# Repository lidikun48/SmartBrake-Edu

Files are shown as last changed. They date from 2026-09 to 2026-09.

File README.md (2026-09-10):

# SmartBrake Edu

SmartBrake Edu adalah prototipe sistem telemetri pengereman berbasis ESP32 yang dikembangkan untuk membantu observasi praktik pengereman sepeda motor pada pelatihan *safety riding*. Sistem memperoleh data tekanan rem depan dan belakang dalam bentuk persentase relatif, membaca kecepatan roda depan dan belakang, menghitung distribusi penggunaan rem F:R, serta menampilkan dan merekam data melalui Web Dashboard pada jaringan Wi-Fi lokal.

Repository ini digunakan sebagai dokumentasi teknis source code dan desain perangkat keras SmartBrake Edu.

## Fitur Utama

- Pembacaan tekanan rem depan dan belakang dalam skala relatif 0–100%.
- Kalibrasi relatif menggunakan metode **Set Zero–Set Max**.
- Pembacaan kecepatan roda depan dan belakang menggunakan sensor *magnetic pickup*.
- Perhitungan distribusi penggunaan rem depan dan belakang (F:R).
- ESP32 sebagai *local access point* dan Web Server.
- Web Dashboard responsif untuk smartphone, tablet, dan laptop.
- Data Logger berbasis browser.
- Brake Test History dan Session Manager.
- Grafik kecepatan dan tekanan selama sesi.
- Brake Event Timeline dan Distribution History.
- Ekspor data hasil sesi.
- Penyimpanan konfigurasi perangkat menggunakan Preferences/NVS.
- Pembaruan firmware melalui OTA.

## Arsitektur Singkat

```text
Sensor Tekanan Depan & Belakang
            |
            v
       Pembacaan ADC
            |
            v
         Filter EMA
            |
            v
   Kalibrasi Relatif
     Set Zero–Set Max
            |
            v
 Persentase Tekanan 0–100%
            |
            +----------------------+
                                   |
Sensor Magnetic Pickup F/R        |
            |                      |
            v                      |
      Pembacaan Pulsa              |
            |                      |
            v                      |
 Perhitungan Kecepatan             |
            |                      |
            +----------+-----------+
                       |
                       v
                     ESP32
                       |
                       v
              Wi-Fi Lokal / HTTP
                       |
                       v
                 Web Dashboard
                       |
                       v
                  Data Logger
```

## Perangkat Keras Utama

- ESP32 DevKit V1
- 2 sensor tekanan hidrolik
- 2 sensor *magnetic pickup*
- PC817 pada antarmuka sensor kecepatan
- rangkaian pengondisi sinyal analog
- LED indikator sistem dan sensor
- sistem catu daya portabel

## Konfigurasi GPIO

| Fungsi | GPIO |
|---|---:|
| Sensor tekanan depan | 32 |
| Sensor tekanan belakang | 33 |
| Sensor kecepatan roda depan | 26 |
| Sensor kecepatan roda belakang | 27 |
| LED system | 2 |
| LED tekanan depan | 5 |
| LED tekanan belakang | 19 |
| LED kecepatan depan | 3 |
| LED kecepatan belakang | 22 |

## Struktur Repository

```text
SmartBrake-Edu/
├── README.md
├── platformio.ini
├── .gitignore
├── src/
│   └── main.cpp
├── docs/
│   ├── hardware/
│   │   └── README.md
│   ├── schematic/
│   │   ├── BrakePressure4.kicad_pro
│   │   ├── BrakePressure4.kicad_sch
│   │   ├── BrakePressure4.kicad_pcb
│   │   └── README.md
│   └── screenshots/
│       └── README.md
└── data/
    └── README.md
```

## Source Code

Firmware utama dan Web Dashboard berada pada:

```text
src/main.cpp
```

Web Dashboard disimpan di dalam firmware menggunakan `PROGMEM`, sehingga HTML, CSS, dan JavaScript berada pada file source yang sama dengan program ESP32.

## Pengembangan dengan PlatformIO

Project menggunakan framework Arduino pada PlatformIO untuk board ESP32 DevKit V1.

Build firmware:

```bash
pio run
```

Konfigurasi build dan metode upload terdapat pada `platformio.ini`.

### Upload USB

Untuk upload melalui kabel USB, gunakan `upload_protocol = esptool` pada `platformio.ini`.

### Upload OTA

Konfigurasi repository menyediakan pengaturan OTA menggunakan `espota` pada alamat lokal perangkat. Pastikan komputer telah terhubung ke jaringan SmartBrake Edu sebelum melakukan upload OTA.

## Konfigurasi Wi-Fi

Demi keamanan repository publik, password Access Point pada `src/main.cpp` menggunakan placeholder:

```cpp
const char* AP_PASS = "CHANGE_ME";
```

Ganti nilai tersebut dengan password yang akan digunakan pada perangkat sebelum melakukan build untuk penggunaan aktual. Jangan menyimpan password pribadi atau kredensial sensitif di repository publik.

## Desain KiCad

Berkas proyek KiCad tersedia pada folder [`docs/schematic`](docs/schematic):

- `BrakePressure4.kicad_sch`
- `BrakePressure4.kicad_pcb`
- `BrakePressure4.kicad_pro`

## Catatan Pengukuran

Nilai tekanan yang ditampilkan SmartBrake Edu merupakan **persentase tekanan relatif** berdasarkan kalibrasi Set Zero–Set Max. Sistem tidak dikalibrasi sebagai instrumen pengukuran tekanan absolut dalam satuan PSI, bar, atau MPa dan tidak mengukur gaya pengereman aktual pada bidang kontak ban dengan permukaan jalan.

Parameter kecepatan digunakan sebagai data pendukung untuk mengamati perubahan laju selama sesi dan tidak dinyatakan sebagai hasil pengukuran kecepatan terkalibrasi terhadap instrumen referensi.

## Konteks Akademik

SmartBrake Edu dikembangkan dalam Proyek Akhir Program Studi D4 Teknik Mesin Otomotif, Fakultas Vokasi, Universitas Negeri Yogyakarta.

**Pengembang:** Chiko Casillas  
**Tahun:** 2026

## Status Repository

- Firmware utama: tersedia.
- Web Dashboard: terintegrasi pada firmware.
- Skematik KiCad: tersedia.
- Layout PCB KiCad: tersedia.
- Konfigurasi PlatformIO: tersedia.
- Folder data dan dokumentasi tambahan: disiapkan untuk contoh data serta dokumentasi akademik yang dapat dipublikasikan.

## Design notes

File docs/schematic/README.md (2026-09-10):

# KiCad Hardware Design

Folder ini memuat berkas desain perangkat keras SmartBrake Edu yang digunakan untuk dokumentasi proyek.

## Berkas

- `BrakePressure4.kicad_sch` — skematik rangkaian SmartBrake Edu.
- `BrakePressure4.kicad_pcb` — layout PCB SmartBrake Edu.
- `BrakePressure4.kicad_pro` — berkas proyek KiCad.

Berkas preferensi lokal KiCad (`*.kicad_prl`) tidak disertakan karena tidak diperlukan untuk membuka atau meninjau desain utama.

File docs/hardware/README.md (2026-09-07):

# Hardware Documentation

Folder ini digunakan untuk dokumentasi perangkat keras SmartBrake Edu, termasuk konfigurasi GPIO, foto perangkat, proses perakitan, dan dokumentasi redesign.

Konfigurasi GPIO final:

| Fungsi | GPIO |
|---|---:|
| Sensor tekanan depan | 32 |
| Sensor tekanan belakang | 33 |
| Sensor kecepatan roda depan | 26 |
| Sensor kecepatan roda belakang | 27 |
| LED System | 2 |
| LED tekanan depan | 5 |
| LED tekanan belakang | 19 |
| LED kecepatan depan | 3 |
| LED kecepatan belakang | 22 |

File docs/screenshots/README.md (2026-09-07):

# Screenshots

Folder ini digunakan untuk dokumentasi tampilan Web Dashboard SmartBrake Edu.

Contoh dokumentasi yang dapat ditempatkan di sini:
- Dashboard utama;
- halaman Data Logger;
- grafik kecepatan dan tekanan;
- Brake Event Timeline;
- Distribution History;
- Session Manager;
- halaman Settings dan kalibrasi relatif.

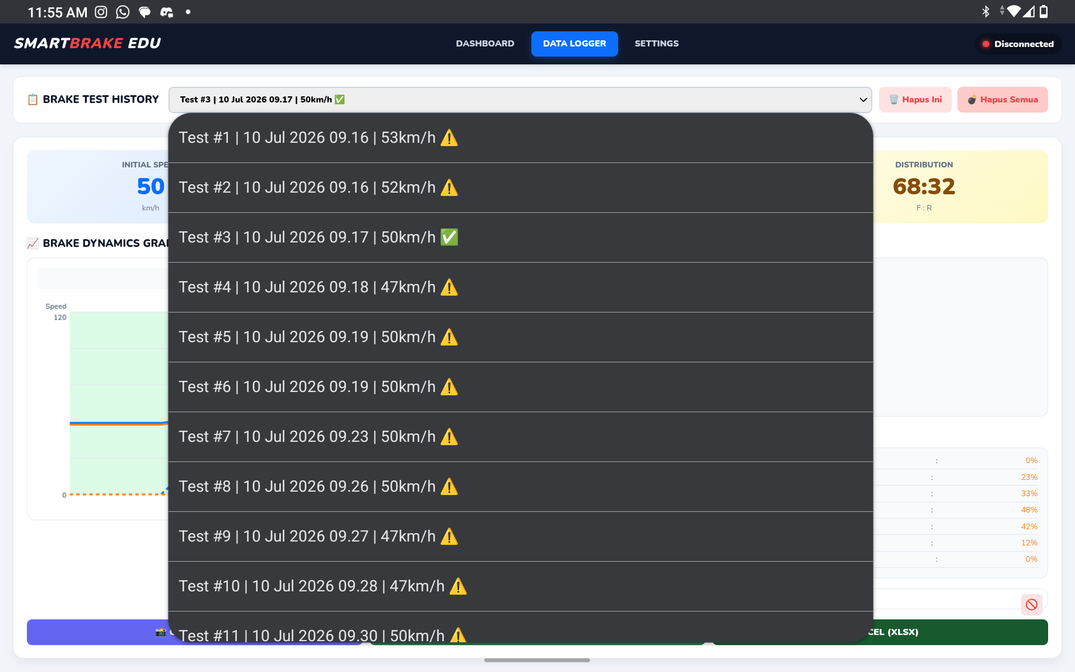
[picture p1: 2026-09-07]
docs/screenshots/Screenshot_20260830-115544.png

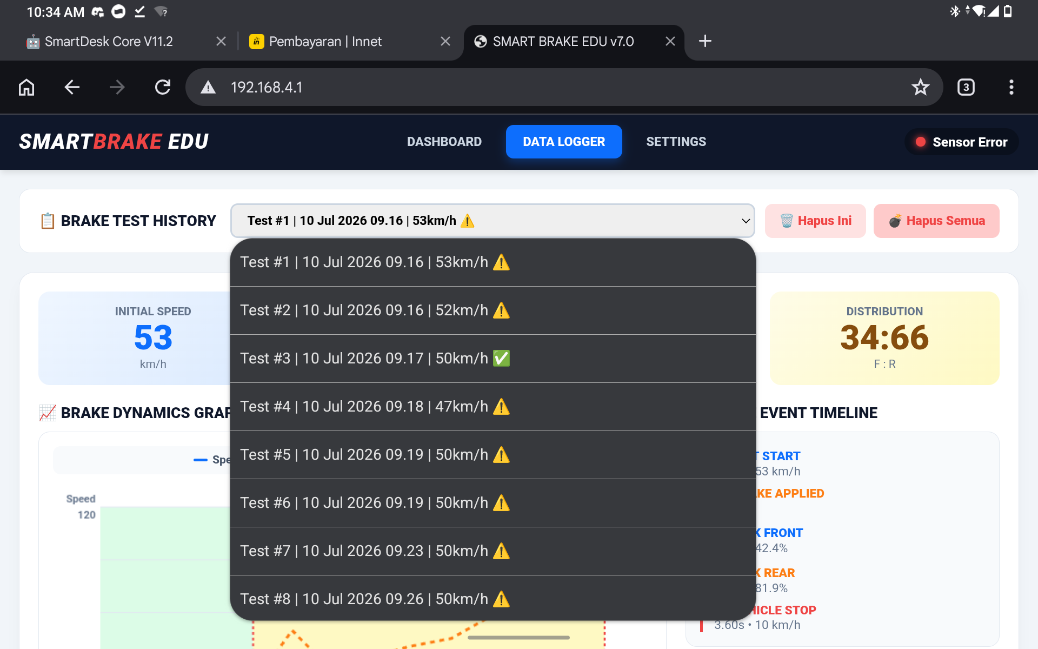
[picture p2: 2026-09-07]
docs/screenshots/Screenshot_20260823-103436.png

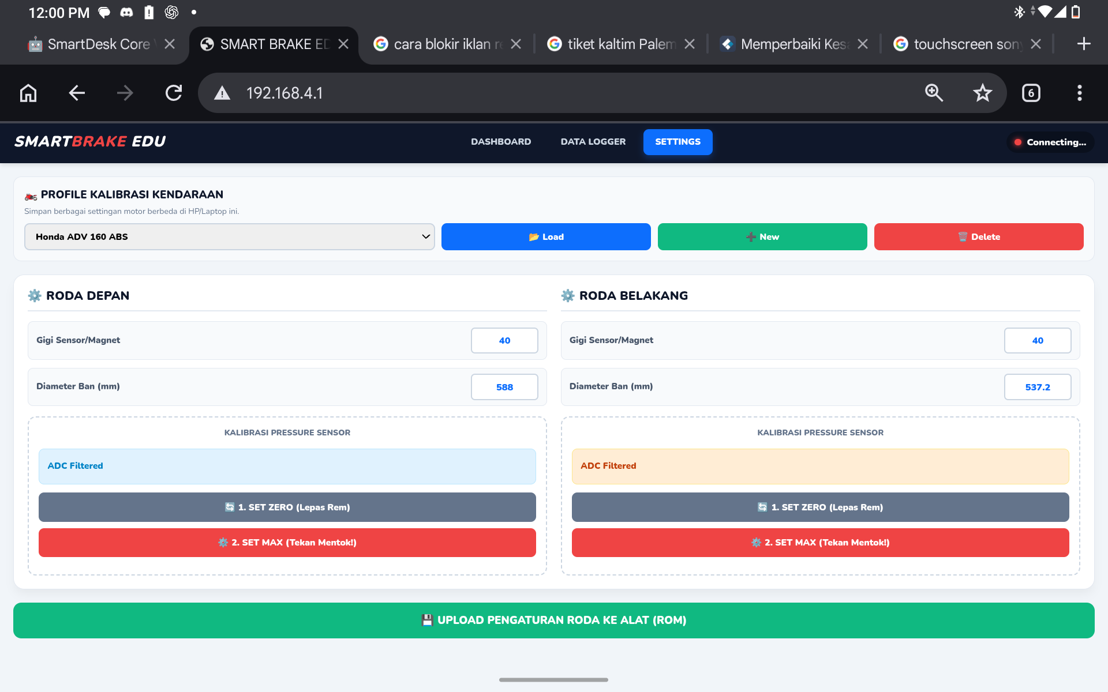
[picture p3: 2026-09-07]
docs/screenshots/Screenshot_20260826-120054.png

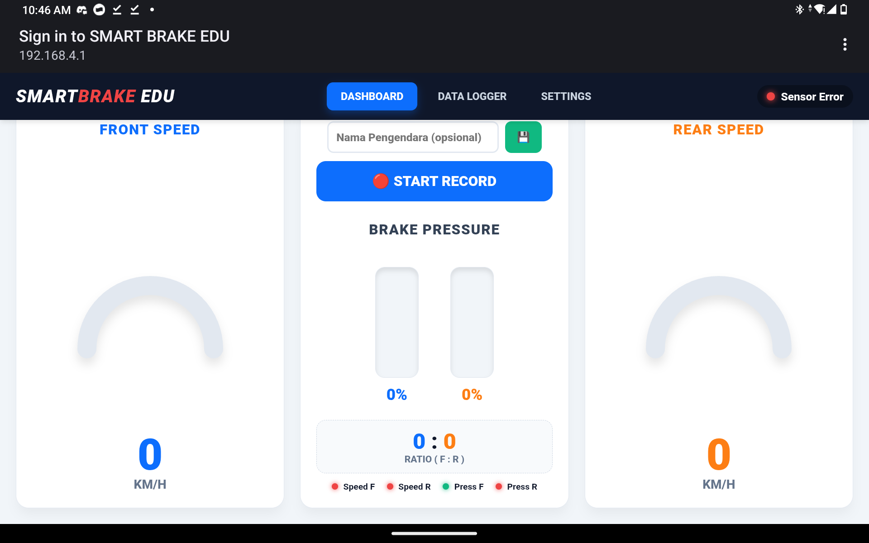
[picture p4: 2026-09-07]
docs/screenshots/Screenshot_20260823-104600.png

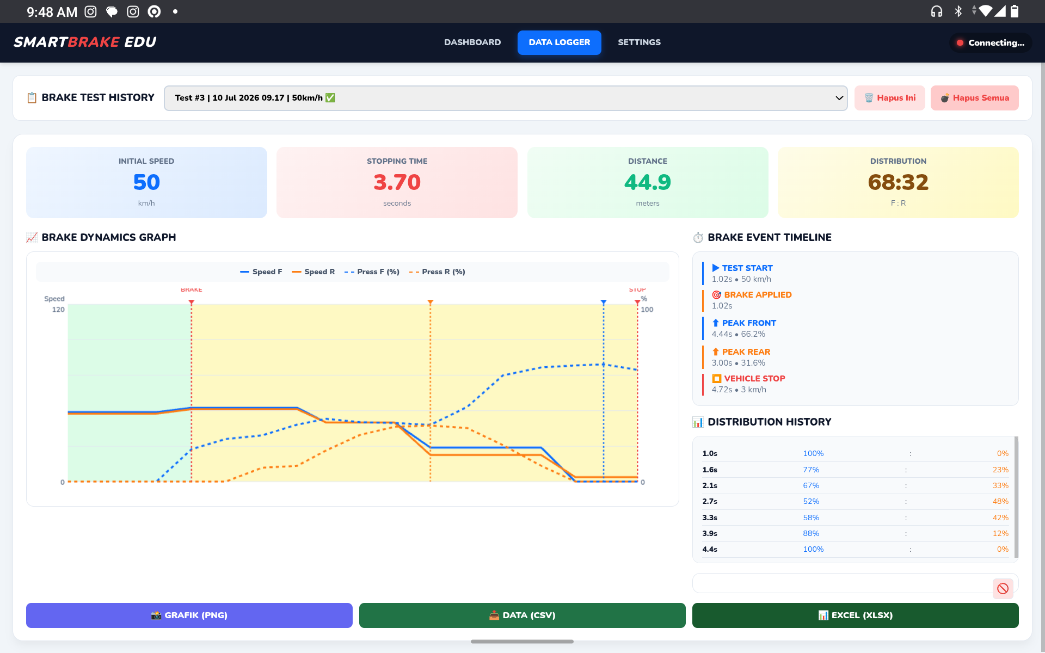
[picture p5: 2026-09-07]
docs/screenshots/Screenshot_20260831-094811.png

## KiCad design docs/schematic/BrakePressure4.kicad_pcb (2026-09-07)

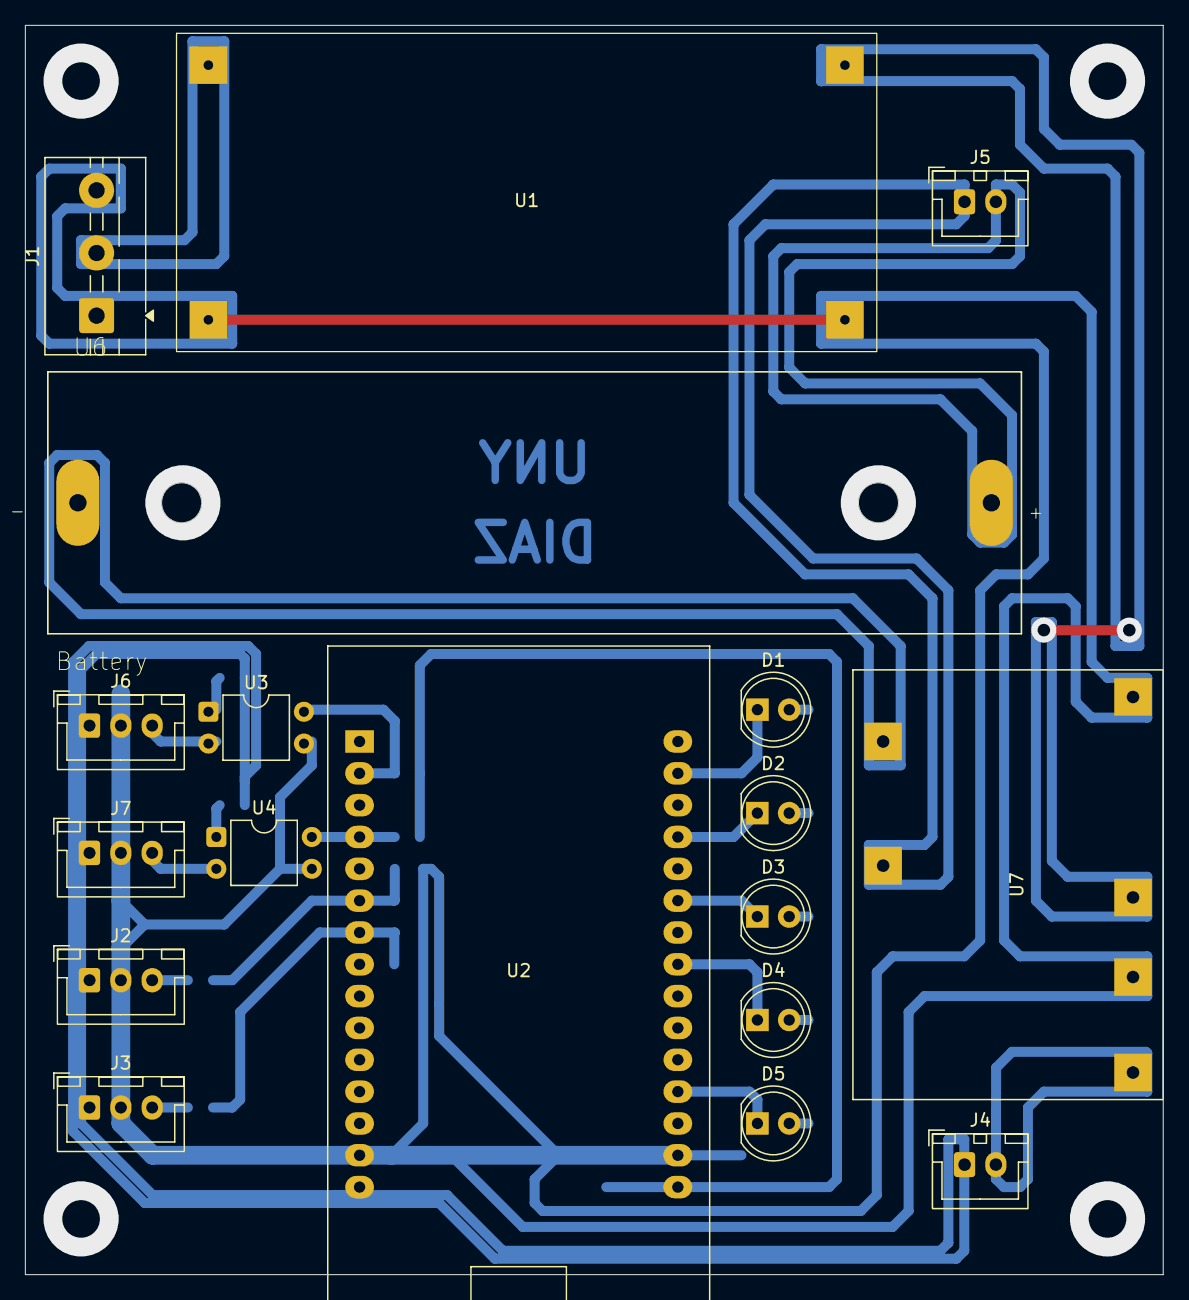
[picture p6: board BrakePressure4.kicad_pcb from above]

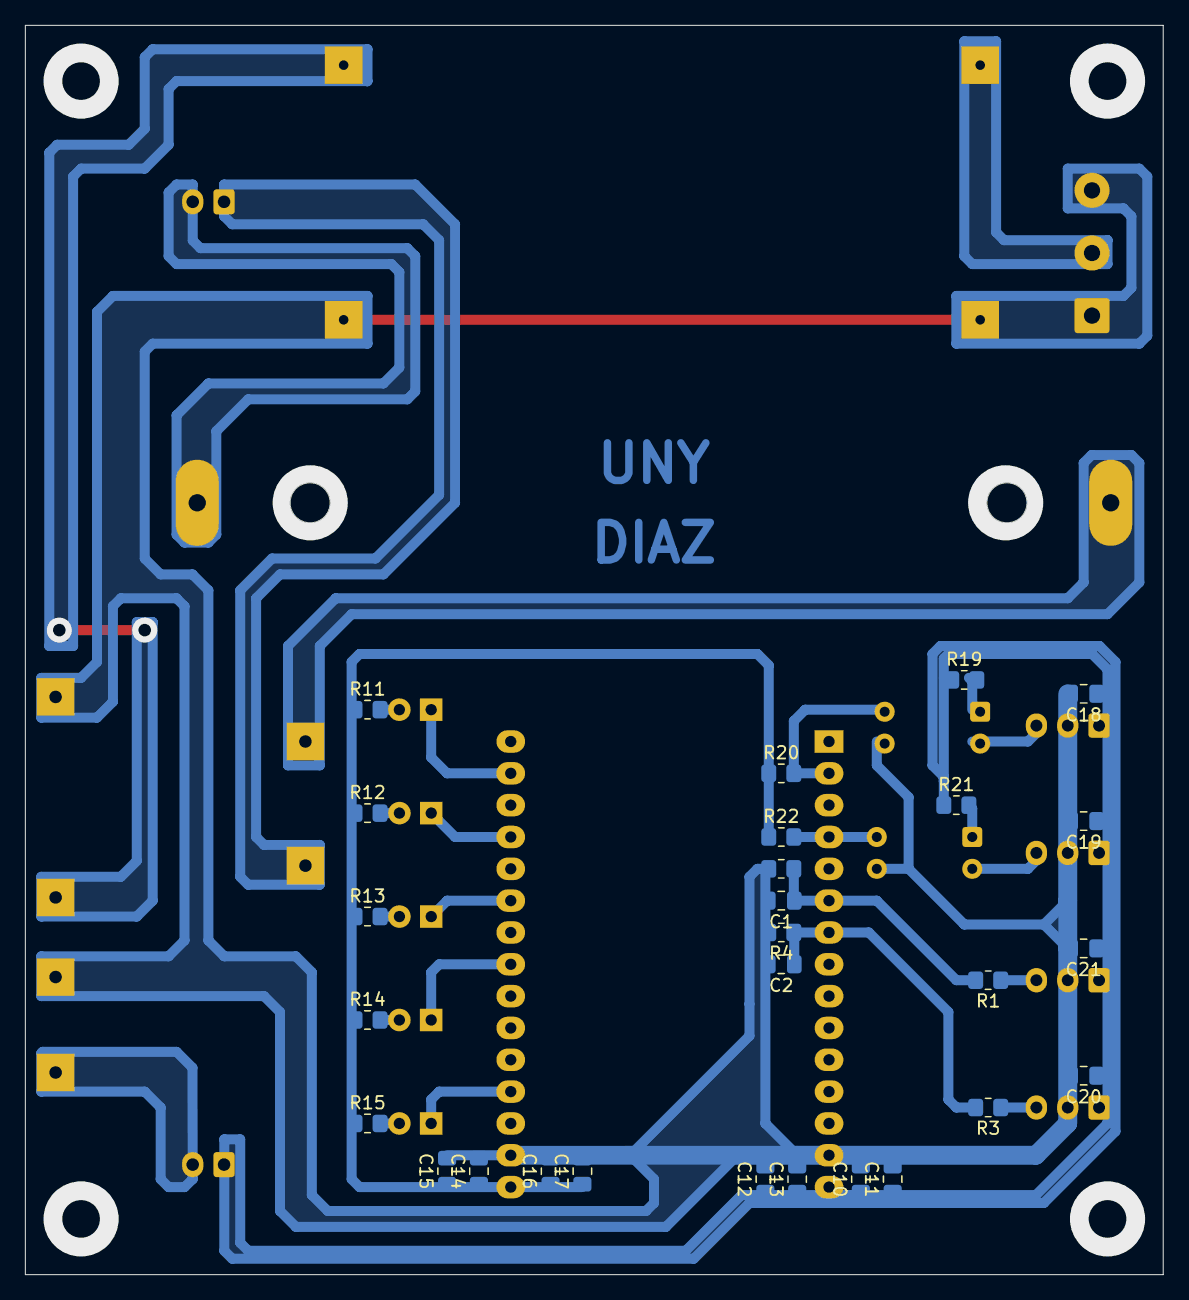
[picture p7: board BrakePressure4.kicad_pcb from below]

Board: 2 copper layers, 90.8 x 99.7 mm, 45 parts (27 on the bottom side), 29 nets.

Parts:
C1, C2, C10, C11, C12, C13, C14, C15, C16, C17, C18, C19, C20, C21: 1uF; C_0805_2012Metric_Pad1.18x1.45mm_HandSolder
D1, D2, D3, D4, D5: LED; LED_D5.0mm_Clear
J1: PWR; TerminalBlock_MaiXu_MX126-5.0-03P_1x03_P5.00mm
J2: SEN1; JST_XH_B3B-XH-A_1x03_P2.50mm_Vertical
J3, J6, J7: SEN2; JST_XH_B3B-XH-A_1x03_P2.50mm_Vertical
J4, J5: Switch; JST_XH_B2B-XH-A_1x02_P2.50mm_Vertical
R1, R3: 4,7k; R_0805_2012Metric_Pad1.20x1.40mm_HandSolder
R2, R4, R19, R21: 10k; R_0805_2012Metric_Pad1.20x1.40mm_HandSolder
R11, R12, R13, R14, R15: 220; R_0805_2012Metric_Pad1.20x1.40mm_HandSolder
R20, R22: 1k; R_0805_2012Metric_Pad1.20x1.40mm_HandSolder
U1: XL4015_Module; XL4015
U2: ESP32_Dev
U3, U4: PC817; DIP-4_W7.62mm
U6: Battery; BAT_BH-18650-PC
U7: Battery_Charger_TP4056; Module_TP4056

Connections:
+3V3: C14.1, C15.1, C16.1, C17.1, R11.1, R12.1, R13.1, R14.1, R15.1, R20.1, R22.1, U2.16 (3v3)
+12V: J1.2, U1.1 (In+)
GND: C1.2, C2.2, C10.2, C11.2, C12.2, C13.2, C14.2, C15.2, C16.2, C17.2, C18.2, C19.2, C20.2, C21.2, J1.1, J1.3, J2.2, J3.2, J6.2, J7.2, R2.2, R4.2, U1.2 (In-), U1.4 (Out-), U2.14 (GND), U2.17 (GND), U3.3, U4.3, U7.2 (OUT-), U7.4 (IN-)
IDO1: D1.1 (K), U2.29 (SCL/IO22)
IDO2: D2.1 (K), U2.27 (RXD/IO3)
IDO3: D3.1 (K), U2.25 (MISO/IO19)
IDO4: D4.1 (K), U2.23 (IO5)
IDON: D5.1 (K), U2.19 (IO2/ADC2_2)
unnamed: D1.2 (A), R11.2
unnamed: D2.2 (A), R12.2
unnamed: D3.2 (A), R13.2
unnamed: D4.2 (A), R14.2
unnamed: D5.2 (A), R15.2
unnamed: J4.2, U7.1 (OUT+)
unnamed: J5.1, U7.5 (B+)
unnamed: J5.2, U6.P
unnamed: J6.3, U3.2
unnamed: J7.3, U4.2
unnamed: R19.2, U3.1
unnamed: R21.2, U4.1
unnamed: U1.3 (Out+), U7.3 (IN+)
unnamed: U6.N, U7.6 (B-)
P_IN1: C1.1, R1.2, R2.1, U2.6 (IO32/ADC1_4)
P_IN2: C2.1, R3.2, R4.1, U2.7 (IP33/ADC1_5)
P_IN3: R20.2, U2.2 (IO36/ADC1_0), U3.4
P_IN4: R22.2, U2.4 (IO34/ADC1_6), U4.4
S_IN1: J2.3, R1.1
S_IN2: J3.3, R3.1
VCC: C10.1, C11.1, C12.1, C13.1, C18.1, C19.1, C20.1, C21.1, J2.1, J3.1, J4.1, J6.1, J7.1, R19.1, R21.1, U2.15 (VIN)

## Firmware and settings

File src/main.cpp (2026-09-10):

#include <Arduino.h>
#include <WiFi.h>
#include <WebServer.h>
#include <ArduinoOTA.h>
#include <Preferences.h>
#include <DNSServer.h>

// =====================================================
// PIN MAP ESP32
// =====================================================
#define LED_SYSTEM          2   
#define LED_FRONT_PRESSURE  5   
#define LED_REAR_PRESSURE   19  
#define LED_FRONT_SPEED     3   
#define LED_REAR_SPEED      22  

#define PIN_ADC_FRONT_PRESSURE 32
#define PIN_ADC_REAR_PRESSURE  33
#define PIN_FRONT_SPEED_SENSOR 26 
#define PIN_REAR_SPEED_SENSOR  27 

// =====================================================
// WIFI AP & CAPTIVE PORTAL SETTINGS
// =====================================================
const char* AP_SSID = "SMART BRAKE EDU";
const char* AP_PASS = "CHANGE_ME";
const char* OTA_HOSTNAME = "SMART-BRAKE-EDU";

const byte DNS_PORT = 53;
DNSServer dnsServer;
WebServer server(80);
Preferences prefs;

// =====================================================
// DATA STRUCTURES
// =====================================================
struct BrakeSetting {
  uint16_t numTooth;
  float diameterMM;
  float maxSpeedKMH;
  int minADC;
  int maxADC;
  float maxPressurePSI;
};

BrakeSetting frontSet = { 40, 588.0, 120.0, 990, 4095, 100.0 };
BrakeSetting rearSet  = { 40, 537.2, 120.0, 990, 4095, 100.0 };

// =====================================================
// GLOBAL MEASUREMENT VARIABLES
// =====================================================
volatile uint32_t frontPulseCount = 0;
volatile uint32_t rearPulseCount = 0;
volatile uint32_t lastFrontPulseUs = 0;
volatile uint32_t lastRearPulseUs = 0;

const uint32_t PULSE_DEBOUNCE_US = 15000;
uint32_t lastFrontPulseCount = 0;
uint32_t lastRearPulseCount = 0;
uint32_t lastSampleMs = 0;
uint32_t lastSpeedSampleMs = 0;

const uint32_t UI_INTERVAL_MS = 100;
const uint32_t SPEED_INTERVAL_MS = 1000;

float emaFrontADC = 0.0;
float emaRearADC = 0.0;
const float ADC_ALPHA = 0.3;

int rawFrontADC = 0;
int rawRearADC = 0;
float frontPressurePSI = 0.0;
float rearPressurePSI = 0.0;
float frontSpeedKMH = 0.0;
float rearSpeedKMH = 0.0;
float frontRatio = 0.0;
float rearRatio = 0.0;
bool frontPressureConnected = false;
bool rearPressureConnected = false;

// =====================================================
// LED MANAGEMENT VARIABLES
// =====================================================
unsigned long lastSystemBlink = 0;
bool systemLedState = false;
volatile bool frontPulseLed = false;
volatile bool rearPulseLed = false;
unsigned long frontPulseLedTimer = 0;
unsigned long rearPulseLedTimer = 0;
const unsigned long PULSE_LED_DURATION = 50;
unsigned long lastPressureLedUpdate = 0;
const unsigned long PRESSURE_LED_INTERVAL = 500;

// =====================================================
// SPEED SENSOR DISCONNECT DETECTION
// =====================================================
unsigned long lastFrontPulseTime = 0;
unsigned long lastRearPulseTime = 0;
const unsigned long SPEED_SENSOR_TIMEOUT = 3000;

// =====================================================
// HTML PAGE - FINAL v7.0
// =====================================================
const char INDEX_HTML[] PROGMEM = R"rawliteral(
<!DOCTYPE html>
<html lang="id">
<head>
<meta charset="UTF-8">
<title>SMART BRAKE EDU v7.0</title>
<meta name="viewport" content="width=device-width, initial-scale=1.0">
<script src="https://cdn.sheetjs.com/xlsx-0.20.0/package/dist/xlsx.full.min.js"></script>
<style>
  @import url('https://fonts.googleapis.com/css2?family=Nunito:wght@400;700;900&display=swap');
  :root { --blue: #0d6efd; --orange: #fd7e14; --bg: #f1f5f9; --dark: #0f172a; --green: #10b981; --red: #ef4444; }
  * { box-sizing: border-box; font-family: 'Nunito', sans-serif; margin: 0; padding: 0; user-select:none; }
  body { background: var(--bg); color: var(--dark); display: flex; flex-direction: column; height: 100vh; overflow-x:hidden; }
  
  .navbar { display: flex; justify-content: space-between; align-items: center; background: var(--dark); padding: 12px 20px; color: white; flex-wrap: wrap; gap: 10px; box-shadow: 0 4px 6px -1px rgba(0,0,0,0.1); z-index: 10;}
  .logo { font-size: 22px; font-weight: 900; font-style: italic; letter-spacing: 1px;}
  .logo span { color: var(--red); }
  .tabs { display: flex; gap: 8px; flex-wrap: wrap; }
  .tab-btn { background: transparent; color: #cbd5e1; border: 2px solid transparent; padding: 8px 16px; border-radius: 8px; font-weight: 800; cursor: pointer; transition: all 0.3s ease; }
  .tab-btn.active { background: var(--blue); color: white; box-shadow: 0 4px 10px rgba(13,110,253,0.3); }
  .conn-status { display: flex; align-items: center; gap: 8px; font-size: 14px; font-weight: 800; background: rgba(0,0,0,0.3); padding: 6px 12px; border-radius: 20px;}
  .conn-dot { width: 10px; height: 10px; background: var(--red); border-radius: 50%; box-shadow: 0 0 8px var(--red); }

  .tab-content { display: none; padding: 20px; flex: 1; overflow-y: auto; }
  .tab-content.active { display: block; }
  .panel-card { background: white; border-radius: 16px; padding: 20px; box-shadow: 0 10px 15px -3px rgba(0,0,0,0.05); border: 1px solid #e2e8f0; }

  .dash-grid { display: grid; grid-template-columns: 1fr 1fr 1fr; gap: 20px; }
  .dash-panel { display: flex; flex-direction: column; align-items: center; justify-content: space-between; text-align:center; }
  .panel-title { font-weight: 900; font-size: 18px; letter-spacing: 1px; margin-bottom: 10px; text-transform: uppercase;}
  
  .gauge-svg { width: 100%; max-width: 200px; overflow: visible; filter: drop-shadow(0px 8px 6px rgba(0,0,0,0.1)); }
  .speed-text { margin-top: -40px; text-align: center; }
  .s-val { font-size: 55px; font-weight: 900; line-height: 1; }
  .s-unit { font-size: 16px; color: #64748b; font-weight: 800; text-transform: uppercase; }
  
  .bars-wrapper { display: flex; justify-content: center; gap: 40px; height: 180px; width: 100%; align-items: flex-end; margin: 20px 0; }
  .bar-col { display: flex; flex-direction: column; align-items: center; height: 100%; justify-content: flex-end;}
  .bar-bg { width: 55px; background: #f1f5f9; border-radius: 12px; height: 140px; position: relative; overflow: hidden; box-shadow: inset 0 4px 6px rgba(0,0,0,0.1); border: 1px solid #e2e8f0;}
  .bar-fill { position: absolute; bottom: 0; left: 0; right: 0; transition: height 0.15s ease-out; border-radius: 0 0 12px 12px;}
  .bar-f { background: linear-gradient(0deg, #1d4ed8, #60a5fa); }
  .bar-r { background: linear-gradient(0deg, #ea580c, #fcd34d); }
  .bar-label { font-weight: 900; font-size: 20px; margin-top: 10px; }

  .ratio-box { background: #f8fafc; padding: 10px 20px; border-radius: 12px; border: 1px dashed #cbd5e1; width: 100%;}
  
  .record-box { background: white; width: 100%; margin-bottom: 15px; }
  .btn-record { width:100%; padding:15px; font-size:18px; font-weight:900; border:none; border-radius:12px; background: var(--blue); color:white; cursor:pointer; transition:all 0.2s;}
  .btn-record.recording { background: var(--red); animation: pulse 1.5s infinite; }
  @keyframes pulse { 0% { box-shadow: 0 0 0 0 rgba(239,68,68,0.7); } 70% { box-shadow: 0 0 0 15px rgba(239,68,68,0); } 100% { box-shadow: 0 0 0 0 rgba(239,68,68,0); } }

  .rider-input { display:flex; gap:8px; margin-bottom:10px; }
  .rider-input input { flex:1; padding:10px; border:2px solid #e2e8f0; border-radius:8px; font-weight:800; font-size:14px; outline:none; }
  .rider-input button { padding:10px 15px; background:var(--green); color:white; border:none; border-radius:8px; font-weight:800; cursor:pointer; }

  .sensor-status { display: flex; justify-content: center; gap: 15px; margin-top: 10px; font-size: 11px; font-weight: 700; }
  .status-dot { display: inline-block; width: 8px; height: 8px; border-radius: 50%; margin-right: 4px; }
  .status-dot.on { background: var(--green); box-shadow: 0 0 6px var(--green); }
  .status-dot.off { background: var(--red); box-shadow: 0 0 6px var(--red); }

  #captiveWarning { animation: shake 0.5s ease-in-out; }
  @keyframes shake { 0%,100%{transform:translateX(0)} 25%{transform:translateX(-5px)} 75%{transform:translateX(5px)} }

  .summary-grid { display: grid; grid-template-columns: 1fr 1fr 1fr 1fr; gap: 15px; margin-bottom: 20px; }
  .summary-card { padding: 15px; border-radius: 12px; text-align: center; }
  .summary-card .label { font-size: 12px; font-weight: 800; color: #64748b; }
  .summary-card .value { font-size: 36px; font-weight: 900; }
  .summary-card .unit { font-size: 12px; color: #64748b; }
  .card-blue { background: linear-gradient(135deg,#eff6ff,#dbeafe); } .card-blue .value { color: var(--blue); }
  .card-red { background: linear-gradient(135deg,#fef2f2,#fee2e2); } .card-red .value { color: var(--red); }
  .card-green { background: linear-gradient(135deg,#f0fdf4,#dcfce7); } .card-green .value { color: var(--green); }
  .card-yellow { background: linear-gradient(135deg,#fefce8,#fef9c3); } .card-yellow .value { color: #854d0e; }

  .logger-layout { display: grid; grid-template-columns: 2fr 1fr; gap: 20px; }
  
  .session-mgr { background: white; padding: 15px 20px; border-radius: 12px; margin-bottom: 20px; display:flex; justify-content:space-between; align-items:center; border: 1px solid #e2e8f0; flex-wrap:wrap; gap:10px;}
  .session-select { padding: 8px 12px; border-radius: 8px; font-weight: 800; border: 2px solid #cbd5e1; outline:none; min-width:250px; }
  .btn-clear { background: #fee2e2; color: var(--red); border: none; padding: 10px 15px; border-radius: 8px; font-weight: 900; cursor: pointer; transition: 0.2s;}
  .btn-clear:hover { background: var(--red); color: white; }
  
  .graph-container { position: relative; width: 100%; height: 400px; background: white; border: 1px solid #e2e8f0; border-radius: 12px; padding: 15px; display: flex; flex-direction: column;}
  .legend-box { display: flex; justify-content: center; gap: 15px; font-size: 12px; font-weight: 800; margin-bottom: 10px; flex-wrap: wrap; background: #f8fafc; padding: 8px; border-radius: 8px;}
  .leg-item { display: flex; align-items: center; gap: 5px; color: #475569;}
  .l-sf { width: 15px; height: 3px; background: var(--blue); border-radius:2px;}
  .l-sr { width: 15px; height: 3px; background: var(--orange); border-radius:2px;}
  .l-pf { width: 15px; height: 0px; border-bottom: 2px dashed var(--blue); }
  .l-pr { width: 15px; height: 0px; border-bottom: 2px dashed var(--orange); }
  #logCanvas { width: 100%; flex: 1; }

  .timeline-box, .dist-box { background: #f8fafc; border-radius: 12px; padding: 15px; border: 1px solid #e2e8f0; font-size: 13px; margin-bottom: 15px; }
  .dist-box { max-height: 200px; overflow-y: auto; font-size: 12px; }
  
  .btn-action { padding: 10px 15px; font-size: 14px; font-weight: 900; color: white; border: none; border-radius: 8px; cursor: pointer; transition:0.2s; }

  #btnToggleGrade { transition: all 0.2s ease; }
  #btnToggleGrade:hover { transform: scale(1.1); box-shadow: 0 2px 8px rgba(0,0,0,0.15); }

  .profile-box { background: #f8fafc; border: 1px solid #e2e8f0; padding: 15px; border-radius: 12px; margin-bottom: 20px; }
  .profile-controls { display: flex; gap: 10px; margin-top: 10px;}
  .btn-prof { flex: 1; padding: 10px; border: none; border-radius: 8px; font-weight: 800; cursor: pointer; color: white; }
  
  .settings-grid { display: grid; grid-template-columns: 1fr 1fr; gap: 20px; }
  .set-title { font-size: 18px; font-weight: 900; margin-bottom: 15px; border-bottom: 2px solid #e2e8f0; padding-bottom: 8px;}
  .input-group { display: flex; justify-content: space-between; align-items: center; margin-bottom: 12px; background: #f8fafc; padding: 8px 12px; border-radius: 8px; border: 1px solid #e2e8f0;}
  .input-group label { font-weight: 800; font-size: 13px; color: #475569;}
  .input-group input { width: 100px; padding: 8px; border: 2px solid #cbd5e1; border-radius: 6px; text-align: center; font-weight: 900; font-size:14px; color: var(--blue); outline:none;}
  
  .calib-box { background: white; padding: 15px; border-radius: 12px; margin-top: 15px; border:2px dashed #cbd5e1;}
  .calib-btn { width: 100%; padding: 12px; border: none; border-radius: 8px; font-weight: 900; cursor: pointer; margin-bottom: 10px; color: white;}
  .btn-zero { background: #64748b; } .btn-zero:hover { background: #475569; }
  .btn-max { background: var(--red); } .btn-max:hover { background: #dc2626; }
  .btn-save-set { background: var(--green); color: white; border: none; padding: 15px; border-radius: 12px; font-weight: 900; font-size: 16px; cursor: pointer; margin-top: 20px; width: 100%; }

  .grade-circle { font-size: 45px; font-weight: 900; line-height: 1; }

  @media (max-width: 900px) {
    .dash-grid, .logger-layout, .settings-grid, .summary-grid { grid-template-columns: 1fr 1fr; }
    .summary-grid { grid-template-columns: 1fr 1fr; }
    .tabs { justify-content: center; width: 100%;}
  }
</style>
</head>
<body>

<div class="navbar">
  <div class="logo">SMART<span>BRAKE</span> EDU</div>
  <div class="tabs">
    <button class="tab-btn active" onclick="switchTab('userTab', this)">DASHBOARD</button>
    <button class="tab-btn" onclick="switchTab('logTab', this)">DATA LOGGER</button>
    <button class="tab-btn" onclick="switchTab('setTab', this)">SETTINGS</button>
  </div>
  <div class="conn-status"><div class="conn-dot" id="connDot"></div><span id="connText">Connecting...</span></div>
</div>

<!-- ==================== DASHBOARD TAB ==================== -->
<div id="userTab" class="tab-content active">
  <div id="captiveWarning" style="display:none; background:#fff3cd; border:2px solid #ff9800; padding:15px; border-radius:12px; margin-bottom:15px; text-align:center;">
    <div style="font-size:40px; margin-bottom:10px;">⚠️</div>
    <div style="font-weight:900; font-size:16px; margin-bottom:5px;">Mode Terbatas Terdeteksi!</div>
    <div style="font-size:13px; color:#64748b; margin-bottom:15px;">Fitur Export & History tidak tersedia di pop-up WiFi.</div>
    <button onclick="openInBrowser()" style="background:#0d6efd; color:white; border:none; padding:12px 25px; border-radius:8px; font-weight:900; font-size:16px; cursor:pointer; width:100%;">🚀 BUKA DI CHROME/SAFARI</button>
    <div style="font-size:11px; color:#64748b; margin-top:10px;">Atau ketik manual: <b>192.168.4.1</b></div>
  </div>

  <div class="dash-grid">
    <div class="panel-card dash-panel">
      <div class="panel-title" style="color:var(--blue);">FRONT SPEED</div>
      <svg viewBox="0 0 100 65" class="gauge-svg">
        <path d="M 10 60 A 40 40 0 0 1 90 60" fill="none" stroke="#e2e8f0" stroke-width="12" stroke-linecap="round"/>
        <path id="svgSpdF" d="M 10 60 A 40 40 0 0 1 90 60" fill="none" stroke="var(--blue)" stroke-width="12" stroke-linecap="round" stroke-dasharray="126" stroke-dashoffset="126" style="transition: stroke-dashoffset 0.2s;"/>
      </svg>
      <div class="speed-text"><div class="s-val" id="txtSpdF" style="color:var(--blue);">0</div><div class="s-unit">km/h</div></div>
    </div>
    
    <div class="panel-card dash-panel" style="justify-content: space-between;">
      <div class="rider-input">
        <input type="text" id="riderName" placeholder="Nama Pengendara (opsional)">
        <button onclick="saveRiderName()" title="Simpan Nama">💾</button>
      </div>
      <div class="record-box">
        <button id="btnRec" class="btn-record" onclick="toggleRecord()">🔴 START RECORD</button>
        <div id="recTime" style="font-weight:900; font-size:22px; color:var(--red); display:none; margin-top:10px;">00:00.0</div>
      </div>
      <div class="panel-title" style="color:#334155; margin-top:10px;">BRAKE PRESSURE</div>
      <div class="bars-wrapper">
        <div class="bar-col"><div class="bar-bg"><div id="barF" class="bar-fill bar-f" style="height:0%;"></div></div><div class="bar-label" style="color:var(--blue);" id="txtPercF">0%</div></div>
        <div class="bar-col"><div class="bar-bg"><div id="barR" class="bar-fill bar-r" style="height:0%;"></div></div><div class="bar-label" style="color:var(--orange);" id="txtPercR">0%</div></div>
      </div>
      <div class="ratio-box">
        <div style="font-weight:900; font-size:28px;"><span style="color:var(--blue)" id="ratF">0</span> : <span style="color:var(--orange)" id="ratR">0</span></div>
        <div style="font-size:12px; font-weight:800; color:#64748b;">RATIO ( F : R )</div>
      </div>
      <div class="sensor-status">
        <span><span class="status-dot" id="dotFS"></span> Speed F</span>
        <span><span class="status-dot" id="dotRS"></span> Speed R</span>
        <span><span class="status-dot" id="dotFP"></span> Press F</span>
        <span><span class="status-dot" id="dotRP"></span> Press R</span>
      </div>
    </div>

    <div class="panel-card dash-panel">
      <div class="panel-title" style="color:var(--orange);">REAR SPEED</div>
      <svg viewBox="0 0 100 65" class="gauge-svg">
        <path d="M 10 60 A 40 40 0 0 1 90 60" fill="none" stroke="#e2e8f0" stroke-width="12" stroke-linecap="round"/>
        <path id="svgSpdR" d="M 10 60 A 40 40 0 0 1 90 60" fill="none" stroke="var(--orange)" stroke-width="12" stroke-linecap="round" stroke-dasharray="126" stroke-dashoffset="126" style="transition: stroke-dashoffset 0.2s;"/>
      </svg>
      <div class="speed-text"><div class="s-val" id="txtSpdR" style="color:var(--orange);">0</div><div class="s-unit">km/h</div></div>
    </div>
  </div>
</div>

<!-- ==================== DATA LOGGER TAB v7.0 ==================== -->
<div id="logTab" class="tab-content">
  <div class="session-mgr">
    <div style="display:flex; align-items:center; gap:15px; flex:1;">
      <div style="font-weight:900; font-size:16px;">📋 BRAKE TEST HISTORY</div>
      <select id="sessionList" class="session-select" onchange="loadSession(this.value)" style="flex:1;">
        <option value="">-- Pilih Hasil Uji --</option>
      </select>
    </div>
    <div style="display:flex; gap:8px;">
      <button class="btn-clear" onclick="deleteSingleSession()">🗑️ Hapus Ini</button>
      <button class="btn-clear" onclick="clearAllSessions()" style="background:#fecaca;">💣 Hapus Semua</button>
    </div>
  </div>

  <div class="panel-card">
    <div class="summary-grid">
      <div class="summary-card card-blue"><div class="label">INITIAL SPEED</div><div class="value" id="sumSpd">0</div><div class="unit">km/h</div></div>
      <div class="summary-card card-red"><div class="label">STOPPING TIME</div><div class="value" id="sumTime">0.00</div><div class="unit">seconds</div></div>
      <div class="summary-card card-green"><div class="label">DISTANCE</div><div class="value" id="sumDist">0.0</div><div class="unit">meters</div></div>
      <div class="summary-card card-yellow"><div class="label">DISTRIBUTION</div><div class="value" id="sumRatio">0:0</div><div class="unit">F : R</div></div>
    </div>

    <div class="logger-layout">
      <div>
        <div style="font-weight:900; font-size:16px; margin-bottom:10px;">📈 BRAKE DYNAMICS GRAPH</div>
        <div class="graph-container">
          <div class="legend-box">
            <div class="leg-item"><div class="l-sf"></div> Speed F</div>
            <div class="leg-item"><div class="l-sr"></div> Speed R</div>
            <div class="leg-item"><div class="l-pf"></div> Press F (%)</div>
            <div class="leg-item"><div class="l-pr"></div> Press R (%)</div>
          </div>
          <canvas id="logCanvas"></canvas>
        </div>
      </div>
      
      <div>
        <div style="font-weight:900; font-size:16px; margin-bottom:10px;">⏱️ BRAKE EVENT TIMELINE</div>
        <div class="timeline-box" id="timelineBox">
          <div style="color:#64748b; text-align:center; padding:20px;">Pilih sesi untuk melihat kronologi</div>
        </div>

        <div style="font-weight:900; font-size:16px; margin:15px 0 10px;">📊 DISTRIBUTION HISTORY</div>
        <div class="dist-box" id="distHistoryBox">
          <div style="color:#64748b; text-align:center; padding:10px;">Data distribusi selama pengereman</div>
        </div>

        <div style="margin-top:15px; text-align:center; background:white; padding:15px; border-radius:12px; border:1px solid #e2e8f0; position:relative;">
          <button id="btnToggleGrade" onclick="toggleGrade()" style="position:absolute; top:8px; right:8px; background:#fee2e2; border:1px solid #e2e8f0; border-radius:6px; width:32px; height:32px; cursor:pointer; font-size:16px; display:flex; align-items:center; justify-content:center;" title="Show Grade">🚫</button>
          <div id="gradeContainer" style="display:none;">
            <div class="grade-circle" id="evGrade">-</div>
            <div style="font-weight:800; font-size:13px; color:#64748b; margin-top:8px;" id="evDesc">Lakukan uji pengereman dulu!</div>
          </div>
        </div>
      </div>
    </div>

    <div style="display:flex; gap:10px; margin-top:15px; flex-wrap:wrap;">
      <button class="btn-action" onclick="exportImage()" style="background:#6366f1; flex:1; min-width:100px;">📸 GRAFIK (PNG)</button>
      <button class="btn-action" onclick="exportCSV()" style="background:#217346; flex:1; min-width:100px;">📥 DATA (CSV)</button>
      <button class="btn-action" onclick="exportExcel()" style="background:#185a2e; flex:1; min-width:100px;">📊 EXCEL (XLSX)</button>
    </div>
  </div>
</div>
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
void loop() {
  dnsServer.processNextRequest();
  ArduinoOTA.handle();
  server.handleClient();
  updateMeasurement();
  updateLEDSystem();
}

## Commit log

2026-09-07 docs: add schematic documentation folder
2026-09-07 Stage final firmware upload part 1
2026-09-07 Stage final firmware upload part 2
2026-09-07 Stage KiCad schematic upload part 1
2026-09-07 Stage KiCad schematic upload part 2
2026-09-07 Add one-time assembly workflow
2026-09-07 Trigger project file assembly
2026-09-07 Stage final firmware chunk 000
2026-09-07 Stage final firmware chunk 001
2026-09-07 Stage final firmware chunk 002
2026-09-07 Stage final firmware chunk 003
2026-09-10 Clean repository and sanitize public firmware
    [BrakePressure4.kicad_pcb, BrakePressure4.kicad_sch]
2026-09-10 Update ignore rules for PlatformIO and KiCad
2026-09-10 Document final KiCad project files
